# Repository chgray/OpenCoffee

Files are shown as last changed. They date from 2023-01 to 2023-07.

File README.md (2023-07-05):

# KiCad
 - to make the file load pcbnew and then do File->Fabrication Outputs.  save a .pos file {CSV, millimeters, seperate files for front/back} -> Generate Position File.  (chgray-keyboard-top-pos.csv)
	A) Change Ref to Designator
	B) Rot to Rotation
	C) Side to Layer
	D) PoxX to "Mid X"
	E) PosY to "Mid Y"
 
 - to make the BOM load eeschema and then do the button ("generate bill of material") BOM -> bom2csv
     you're looking for chgray-keyboard.csv
	A) Change Reference to "Designator"
	B) Change Datasheet to "JLCPCB Part #"
	C) Value to Comment

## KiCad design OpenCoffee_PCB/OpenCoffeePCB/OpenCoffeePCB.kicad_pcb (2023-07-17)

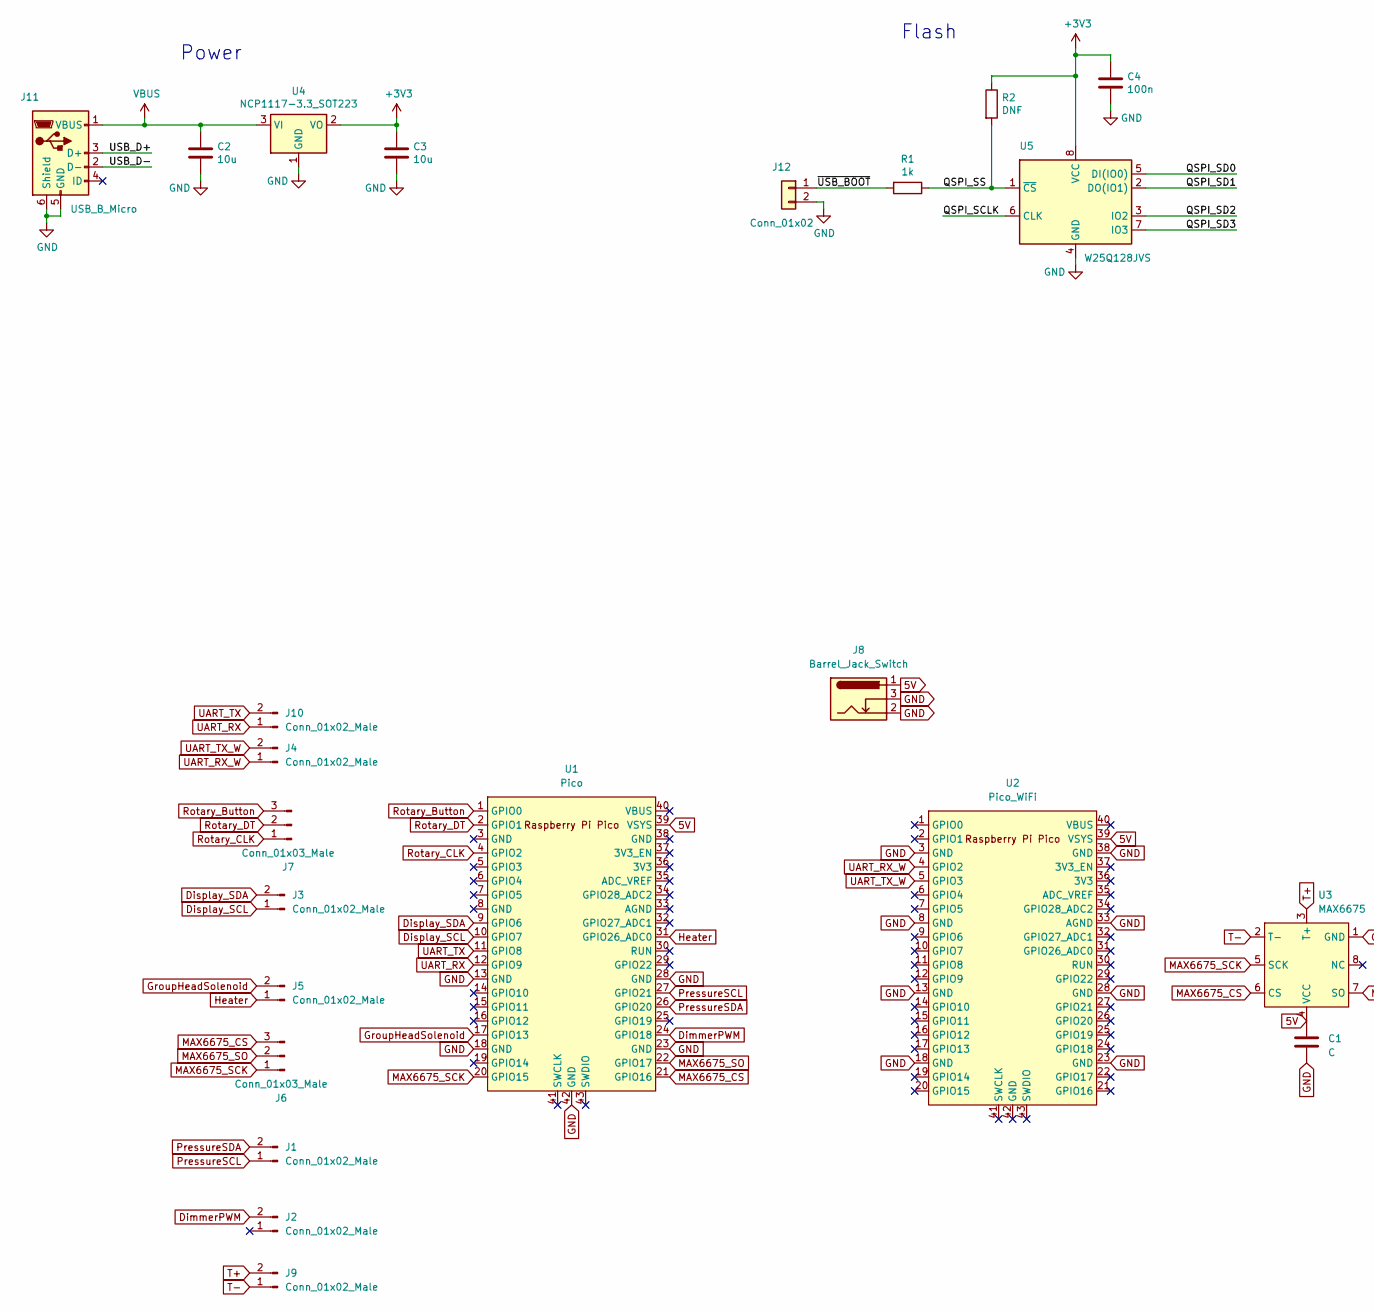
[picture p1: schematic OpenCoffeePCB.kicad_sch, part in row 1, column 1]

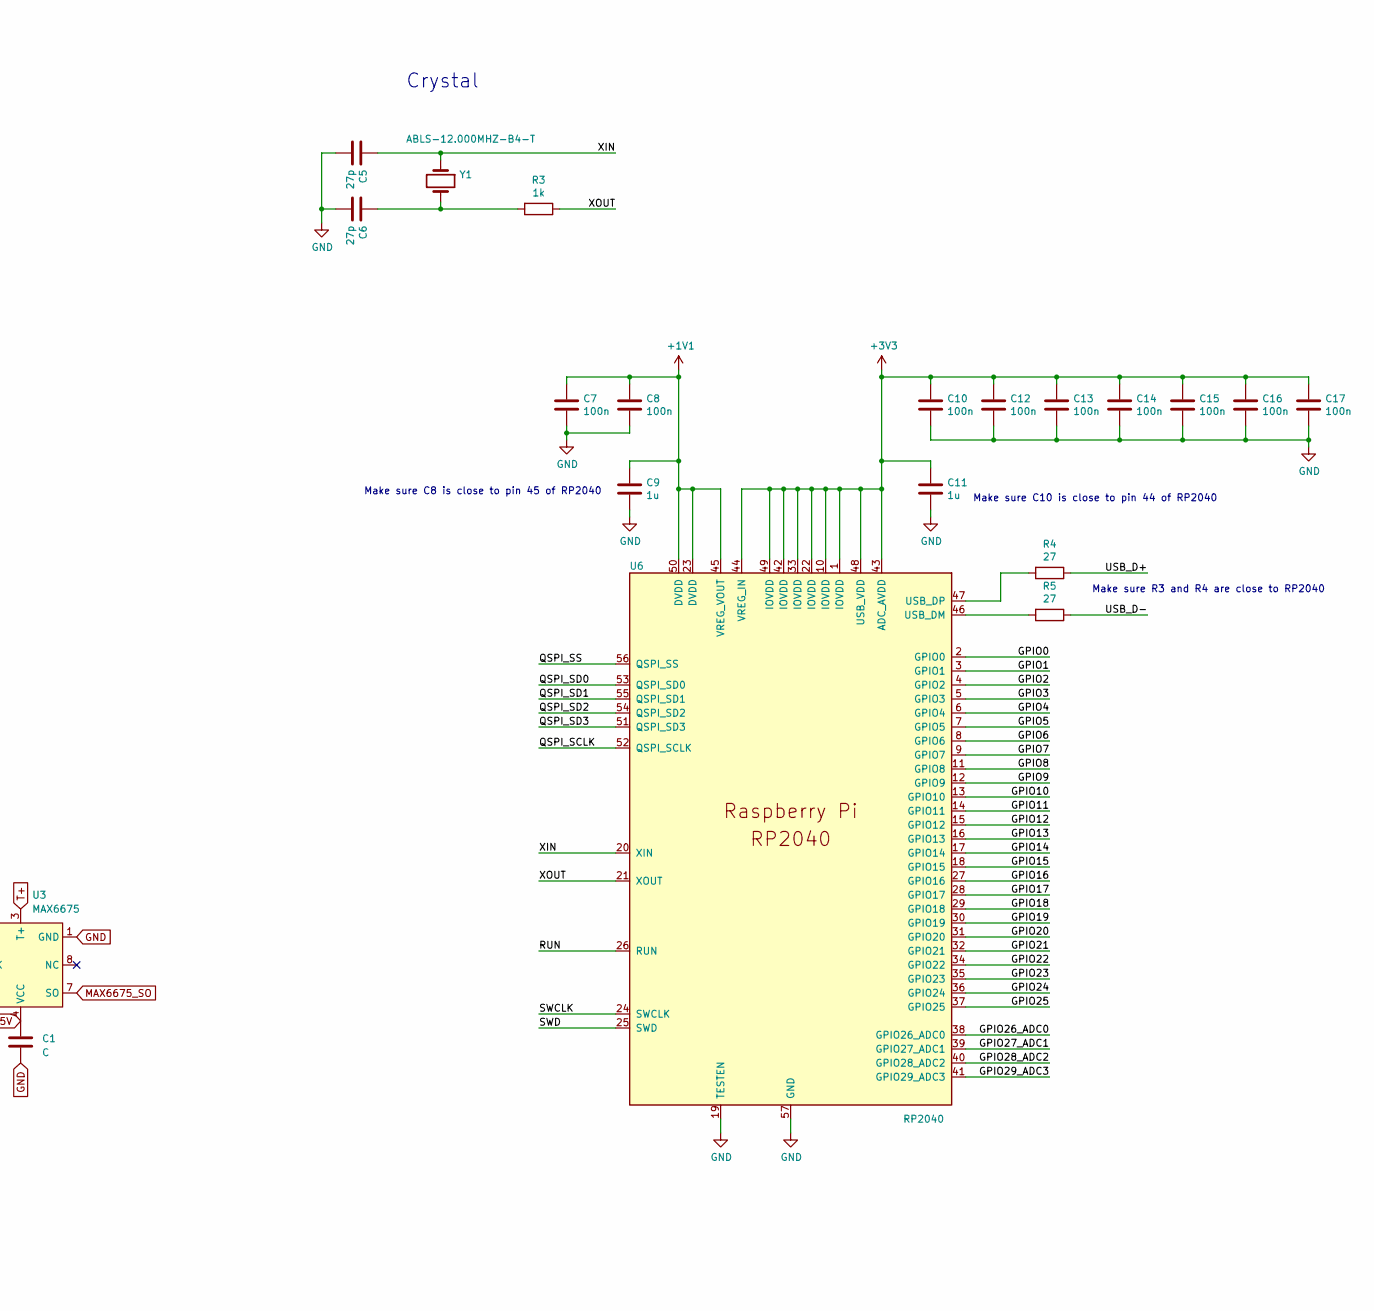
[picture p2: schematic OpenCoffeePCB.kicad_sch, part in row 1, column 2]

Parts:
C1: C; C_0805_2012Metric
C2, C3: 10u; C_0805_2012Metric
C4, C7, C8, C10, C12, C13, C14, C15, C16, C17: 100n; C_0402_1005Metric
C5, C6: 27p; C_0402_1005Metric
C9, C11: 1u; C_0402_1005Metric
J1, J2, J3, J4, J5, J9, J10: Conn_01x02_Male; Molex_KK-254_AE-6410-02A_1x02_P2.54mm_Vertical
J6, J7: Conn_01x03_Male; Molex_KK-254_AE-6410-03A_1x03_P2.54mm_Vertical
J8: Barrel_Jack_Switch; BarrelJack_GCT_DCJ200-10-A_Horizontal
J11: USB_B_Micro; USB_Micro-B_Amphenol_10103594-0001LF_Horizontal_modified
J12: Conn_01x02; PinHeader_1x02_P2.54mm_Vertical
R1, R3: 1k; C_0402_1005Metric
R2: DNF; C_0402_1005Metric
R4, R5: 27; C_0402_1005Metric
U1: Pico; RPi_Pico_SMD_TH
U2: Pico_WiFi; RPi_Pico_SMD_TH_WIFI
U3: MAX6675
U4: NCP1117-3.3_SOT223; SOT-223-3_TabPin2
U5: W25Q128JVS; SOIC-8_5.23x5.23mm_P1.27mm
U6: RP2040; RP2040-QFN-56
Y1: ABLS-12.000MHZ-B4-T; Crystal_SMD_HC49-US

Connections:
5V: C1.1, J8.1, U1.39 (VSYS), U2.39 (VSYS), U3.4 (VCC)
+1V1: C7.1, C8.1, C9.1, U6.23 (DVDD), U6.45 (VREG_VOUT), U6.50 (DVDD)
+3V3: C3.1, C4.1, C10.1, C11.1, C12.1, C13.1, C14.1, C15.1, C16.1, C17.1, R2.1, U4.2 (VO), U5.8 (VCC), U6.1 (IOVDD), U6.10 (IOVDD), U6.22 (IOVDD), U6.33 (IOVDD), U6.42 (IOVDD), U6.43 (ADC_AVDD), U6.44 (VREG_IN), U6.48 (USB_VDD), U6.49 (IOVDD)
/GPIO0: U6.2 (GPIO0)
/GPIO1: U6.3 (GPIO1)
/GPIO2: U6.4 (GPIO2)
/GPIO3: U6.5 (GPIO3)
/GPIO4: U6.6 (GPIO4)
/GPIO5: U6.7 (GPIO5)
/GPIO6: U6.8 (GPIO6)
/GPIO7: U6.9 (GPIO7)
/GPIO8: U6.11 (GPIO8)
/GPIO9: U6.12 (GPIO9)
/GPIO10: U6.13 (GPIO10)
/GPIO11: U6.14 (GPIO11)
/GPIO12: U6.15 (GPIO12)
/GPIO13: U6.16 (GPIO13)
/GPIO14: U6.17 (GPIO14)
/GPIO15: U6.18 (GPIO15)
/GPIO16: U6.27 (GPIO16)
/GPIO17: U6.28 (GPIO17)
/GPIO18: U6.29 (GPIO18)
/GPIO19: U6.30 (GPIO19)
/GPIO20: U6.31 (GPIO20)
/GPIO21: U6.32 (GPIO21)
/GPIO22: U6.34 (GPIO22)
/GPIO23: U6.35 (GPIO23)
/GPIO24: U6.36 (GPIO24)
/GPIO25: U6.37 (GPIO25)
/GPIO26_ADC0: U6.38 (GPIO26_ADC0)
/GPIO27_ADC1: U6.39 (GPIO27_ADC1)
/GPIO28_ADC2: U6.40 (GPIO28_ADC2)
/GPIO29_ADC3: U6.41 (GPIO29_ADC3)
/QSPI_SCLK: U5.6 (CLK), U6.52 (QSPI_SCLK)
/QSPI_SD0: U5.5 (DI(IO0)), U6.53 (QSPI_SD0)
/QSPI_SD1: U5.2 (DO(IO1)), U6.55 (QSPI_SD1)
/QSPI_SD2: U5.3 (IO2), U6.54 (QSPI_SD2)
/QSPI_SD3: U5.7 (IO3), U6.51 (QSPI_SD3)
/QSPI_SS: R1.1, R2.2, U5.1 (~CS), U6.56 (QSPI_SS)
/RUN: U6.26 (RUN)
/SWCLK: U6.24 (SWCLK)
/SWD: U6.25 (SWD)
/USB_D+: J11.3 (D+), R4.1
/USB_D-: J11.2 (D-), R5.1
/XIN: C5.1, U6.20 (XIN), Y1.1
/XOUT: R3.1, U6.21 (XOUT)
/~USB_BOOT: J12.1, R1.2
DimmerPWM: J2.2, U1.24 (GPIO18)
Display_SCL: J3.1, U1.10 (GPIO7)
Display_SDA: J3.2, U1.9 (GPIO6)
GND: C1.2, C2.2, C3.2, C4.2, C5.2, C6.2, C7.2, C8.2, C9.2, C10.2, C11.2, C12.2, C13.2, C14.2, C15.2, C16.2, C17.2, J8.2, J8.3, J11.5 (GND), J11.6 (Shield), J12.2, U1.13 (GND), U1.18 (GND), U1.23 (GND), U1.28 (GND), U1.42 (GND), U2.3 (GND), U2.8 (GND), U2.13 (GND), U2.18 (GND), U2.23 (GND), U2.28 (GND), U2.33 (AGND), U2.38 (GND), U3.1 (GND), U4.1 (GND), U5.4 (GND), U6.19 (TESTEN), U6.57 (GND)
GroupHeadSolenoid: J5.2, U1.17 (GPIO13)
Heater: J5.1, U1.31 (GPIO26_ADC0)
MAX6675_CS: J6.3, U1.21 (GPIO16), U3.6 (CS)
MAX6675_SCK: J6.1, U1.20 (GPIO15), U3.5 (SCK)
MAX6675_SO: J6.2, U1.22 (GPIO17), U3.7 (SO)
unnamed: C6.1, R3.2, Y1.2
unnamed: R5.2, U6.46 (USB_DM)
unnamed: R4.2, U6.47 (USB_DP)
PressureSCL: J1.1, U1.27 (GPIO21)
PressureSDA: J1.2, U1.26 (GPIO20)
Rotary_Button: J7.3, U1.1 (GPIO0)
Rotary_CLK: J7.1, U1.4 (GPIO2)
Rotary_DT: J7.2, U1.2 (GPIO1)
T+: J9.2, U3.3 (T+)
T-: J9.1, U3.2 (T-)
UART_RX: J10.1, U1.12 (GPIO9)
UART_RX_W: J4.1, U2.4 (GPIO2)
UART_TX: J10.2, U1.11 (GPIO8)
UART_TX_W: J4.2, U2.5 (GPIO3)
VBUS: C2.1, J11.1 (VBUS), U4.3 (VI)

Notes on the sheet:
Make sure C8 is close to pin 45 of RP2040
Power
Make sure C10 is close to pin 44 of RP2040
Crystal
Flash
Make sure R3 and R4 are close to RP2040

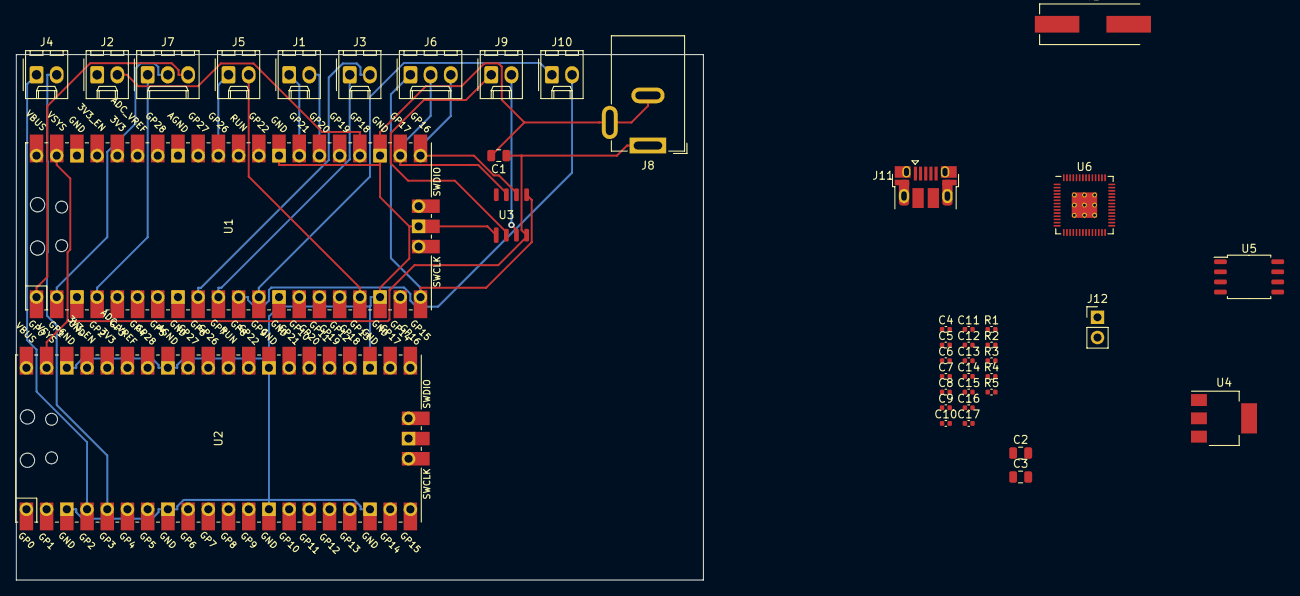
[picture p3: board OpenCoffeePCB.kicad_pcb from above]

Board: 2 copper layers, 86.4 x 66.0 mm, 41 parts (0 on the bottom side), 38 nets.

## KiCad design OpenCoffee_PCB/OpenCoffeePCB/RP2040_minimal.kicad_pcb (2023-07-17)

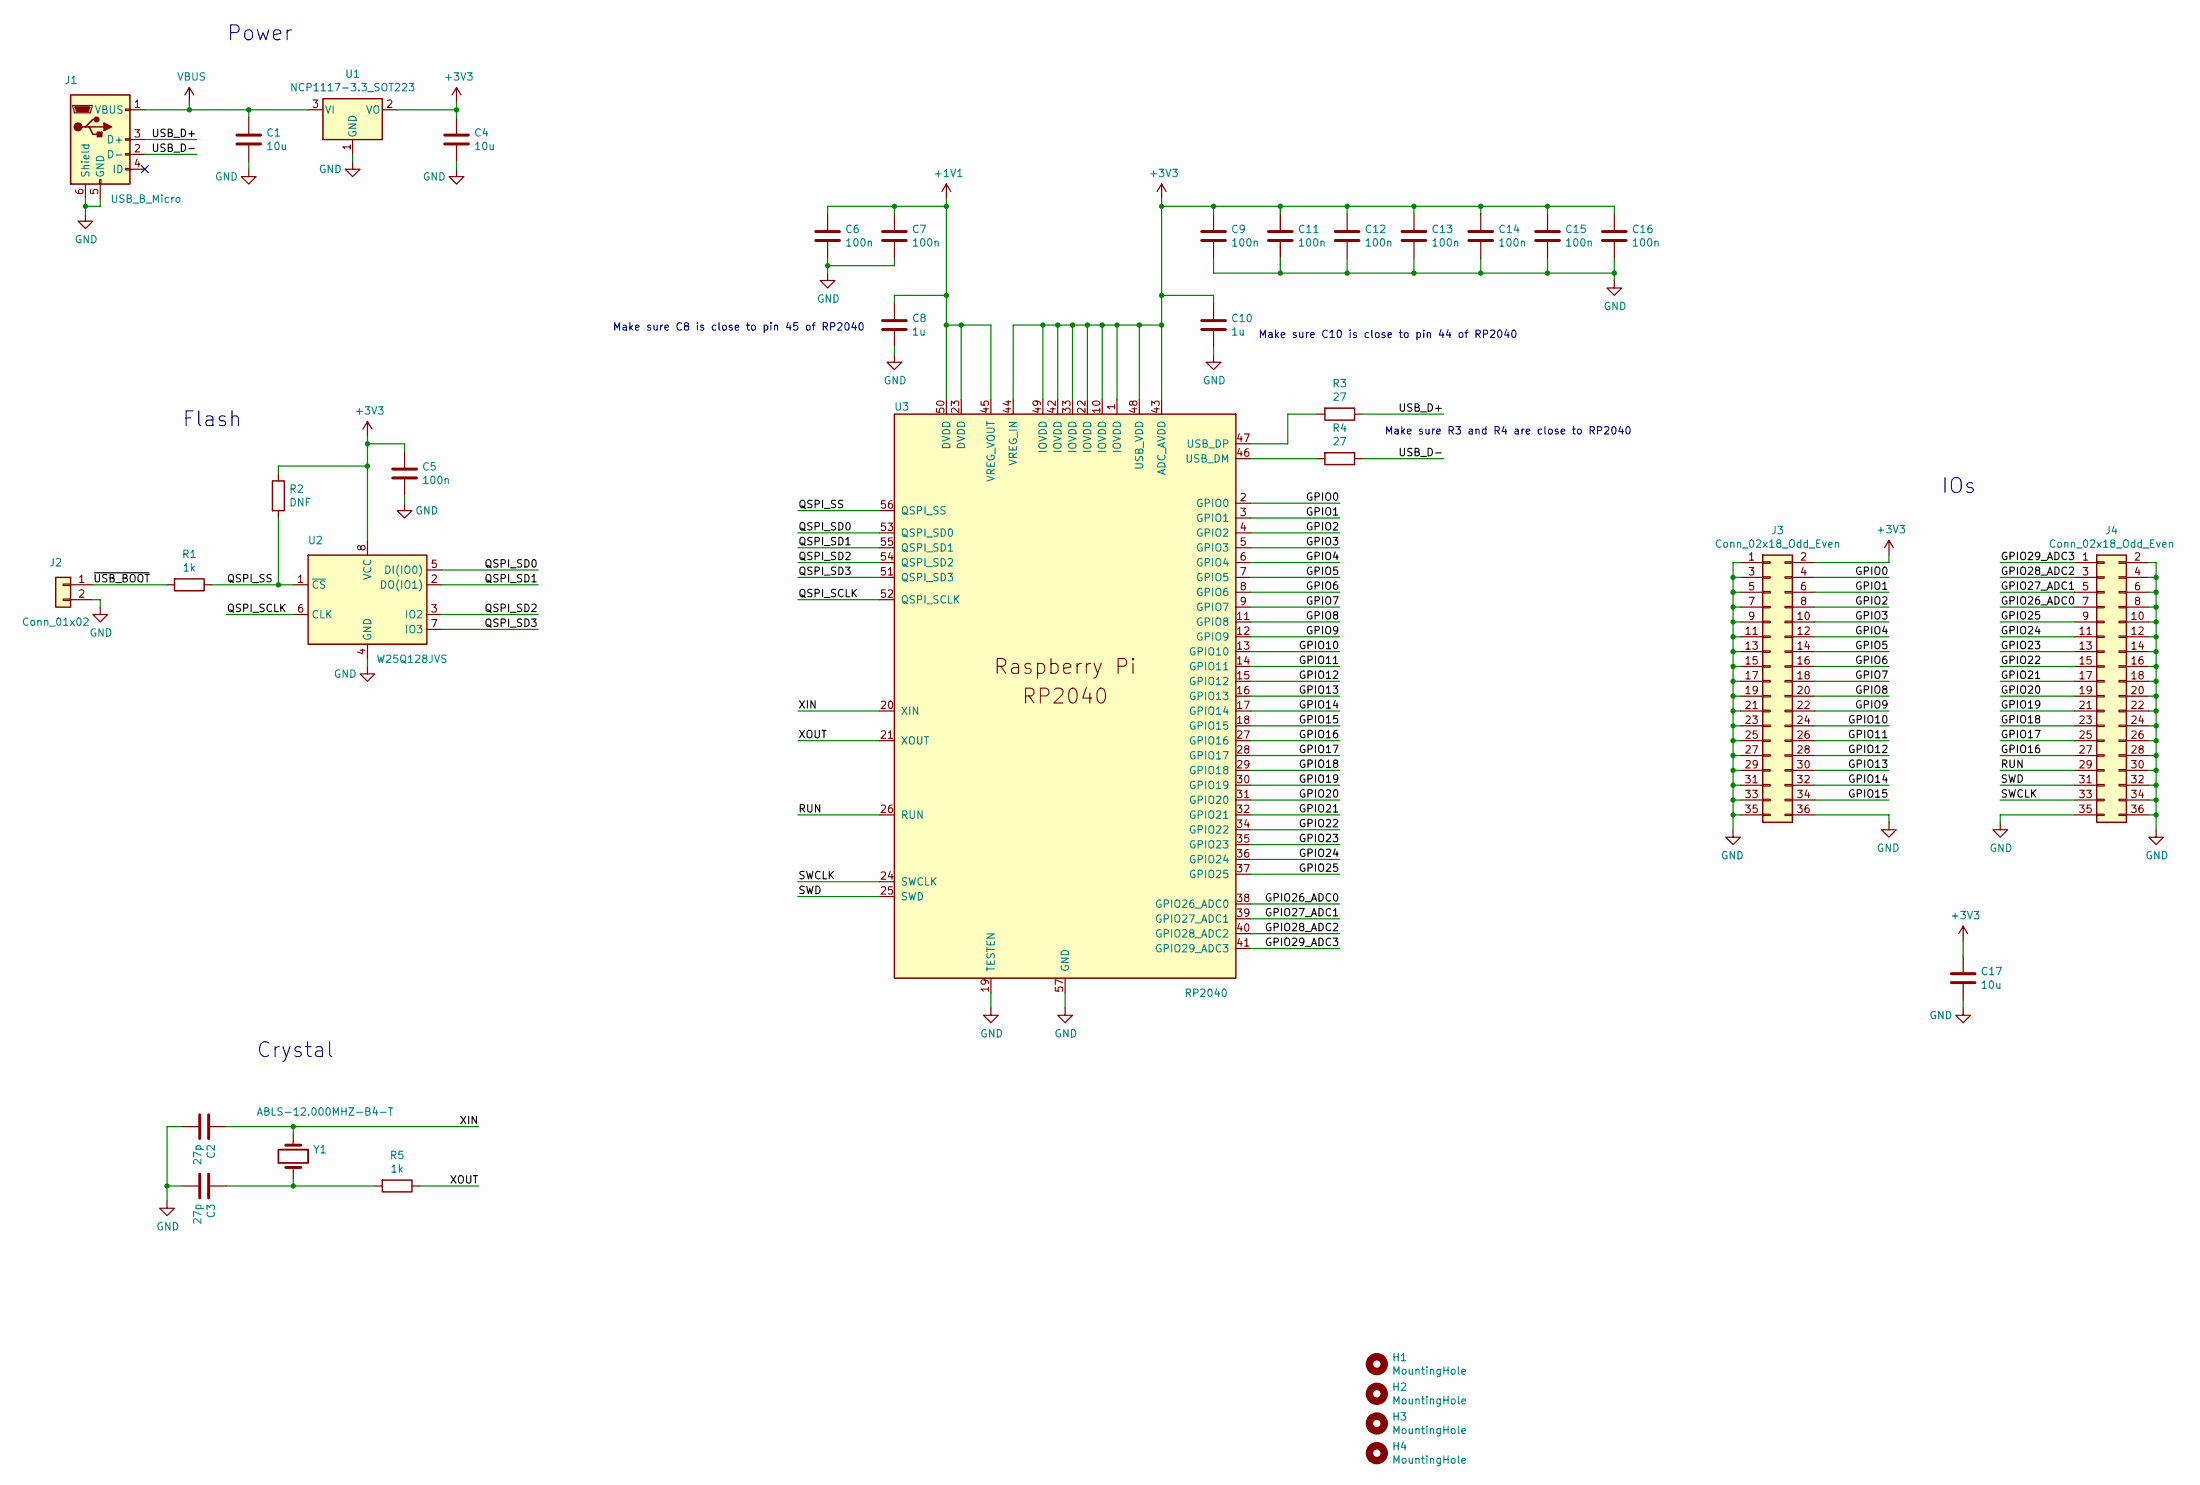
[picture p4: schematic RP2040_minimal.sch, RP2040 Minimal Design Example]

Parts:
C1, C4, C17: 10u; C_0805_2012Metric
C2, C3: 27p; C_0402_1005Metric
C5, C6, C7, C9, C11, C12, C13, C14, C15, C16: 100n; C_0402_1005Metric
C8, C10: 1u; C_0402_1005Metric
H1, H2, H3, H4: MountingHole; MountingHole_2.7mm_M2.5
J1: USB_B_Micro; USB_Micro-B_Amphenol_10103594-0001LF_Horizontal_modified
J2: Conn_01x02; PinHeader_1x02_P2.54mm_Vertical
J3, J4: Conn_02x18_Odd_Even; PinHeader_2x18_P2.54mm_Vertical
R1, R5: 1k; C_0402_1005Metric
R2: DNF; C_0402_1005Metric
R3, R4: 27; C_0402_1005Metric
U1: NCP1117-3.3_SOT223; SOT-223-3_TabPin2
U2: W25Q128JVS; SOIC-8_5.23x5.23mm_P1.27mm
U3: RP2040; RP2040-QFN-56
Y1: ABLS-12.000MHZ-B4-T; Crystal_SMD_HC49-US

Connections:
+1V1: C6.1, C7.1, C8.1, U3.23 (DVDD), U3.45 (VREG_VOUT), U3.50 (DVDD)
+3V3: C4.1, C5.1, C9.1, C10.1, C11.1, C12.1, C13.1, C14.1, C15.1, C16.1, C17.1, J3.2, R2.1, U1.2 (VO), U2.8 (VCC), U3.1 (IOVDD), U3.10 (IOVDD), U3.22 (IOVDD), U3.33 (IOVDD), U3.42 (IOVDD), U3.43 (ADC_AVDD), U3.44 (VREG_IN), U3.48 (USB_VDD), U3.49 (IOVDD)
/GPIO0: J3.4, U3.2 (GPIO0)
/GPIO1: J3.6, U3.3 (GPIO1)
/GPIO2: J3.8, U3.4 (GPIO2)
/GPIO3: J3.10, U3.5 (GPIO3)
/GPIO4: J3.12, U3.6 (GPIO4)
/GPIO5: J3.14, U3.7 (GPIO5)
/GPIO6: J3.16, U3.8 (GPIO6)
/GPIO7: J3.18, U3.9 (GPIO7)
/GPIO8: J3.20, U3.11 (GPIO8)
/GPIO9: J3.22, U3.12 (GPIO9)
/GPIO10: J3.24, U3.13 (GPIO10)
/GPIO11: J3.26, U3.14 (GPIO11)
/GPIO12: J3.28, U3.15 (GPIO12)
/GPIO13: J3.30, U3.16 (GPIO13)
/GPIO14: J3.32, U3.17 (GPIO14)
/GPIO15: J3.34, U3.18 (GPIO15)
/GPIO16: J4.27, U3.27 (GPIO16)
/GPIO17: J4.25, U3.28 (GPIO17)
/GPIO18: J4.23, U3.29 (GPIO18)
/GPIO19: J4.21, U3.30 (GPIO19)
/GPIO20: J4.19, U3.31 (GPIO20)
/GPIO21: J4.17, U3.32 (GPIO21)
/GPIO22: J4.15, U3.34 (GPIO22)
/GPIO23: J4.13, U3.35 (GPIO23)
/GPIO24: J4.11, U3.36 (GPIO24)
/GPIO25: J4.9, U3.37 (GPIO25)
/GPIO26_ADC0: J4.7, U3.38 (GPIO26_ADC0)
/GPIO27_ADC1: J4.5, U3.39 (GPIO27_ADC1)
/GPIO28_ADC2: J4.3, U3.40 (GPIO28_ADC2)
/GPIO29_ADC3: J4.1, U3.41 (GPIO29_ADC3)
/QSPI_SCLK: U2.6 (CLK), U3.52 (QSPI_SCLK)
/QSPI_SD0: U2.5 (DI(IO0)), U3.53 (QSPI_SD0)
/QSPI_SD1: U2.2 (DO(IO1)), U3.55 (QSPI_SD1)
/QSPI_SD2: U2.3 (IO2), U3.54 (QSPI_SD2)
/QSPI_SD3: U2.7 (IO3), U3.51 (QSPI_SD3)
/QSPI_SS: R1.1, R2.2, U2.1 (~CS), U3.56 (QSPI_SS)
/RUN: J4.29, U3.26 (RUN)
/SWCLK: J4.33, U3.24 (SWCLK)
/SWD: J4.31, U3.25 (SWD)
/USB_D+: J1.3 (D+), R3.1
/USB_D-: J1.2 (D-), R4.1
/XIN: C2.1, U3.20 (XIN), Y1.1
/XOUT: R5.1, U3.21 (XOUT)
/~USB_BOOT: J2.1, R1.2
GND: C1.2, C2.2, C3.2, C4.2, C5.2, C6.2, C7.2, C8.2, C9.2, C10.2, C11.2, C12.2, C13.2, C14.2, C15.2, C16.2, C17.2, J1.5 (GND), J1.6 (Shield), J2.2, J3.1, J3.3, J3.5, J3.7, J3.9, J3.11, J3.13, J3.15, J3.17, J3.19, J3.21, J3.23, J3.25, J3.27, J3.29, J3.31, J3.33, J3.35, J3.36, J4.2, J4.4, J4.6, J4.8, J4.10, J4.12, J4.14, J4.16, J4.18, J4.20, J4.22, J4.24, J4.26, J4.28, J4.30, J4.32, J4.34, J4.35, J4.36, U1.1 (GND), U2.4 (GND), U3.19 (TESTEN), U3.57 (GND)
unnamed: C3.1, R5.2, Y1.2
unnamed: R3.2, U3.47 (USB_DP)
unnamed: R4.2, U3.46 (USB_DM)
VBUS: C1.1, J1.1 (VBUS), U1.3 (VI)

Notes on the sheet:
Make sure C10 is close to pin 44 of RP2040
Make sure C8 is close to pin 45 of RP2040
Crystal
Flash
Power
IOs
Make sure R3 and R4 are close to RP2040

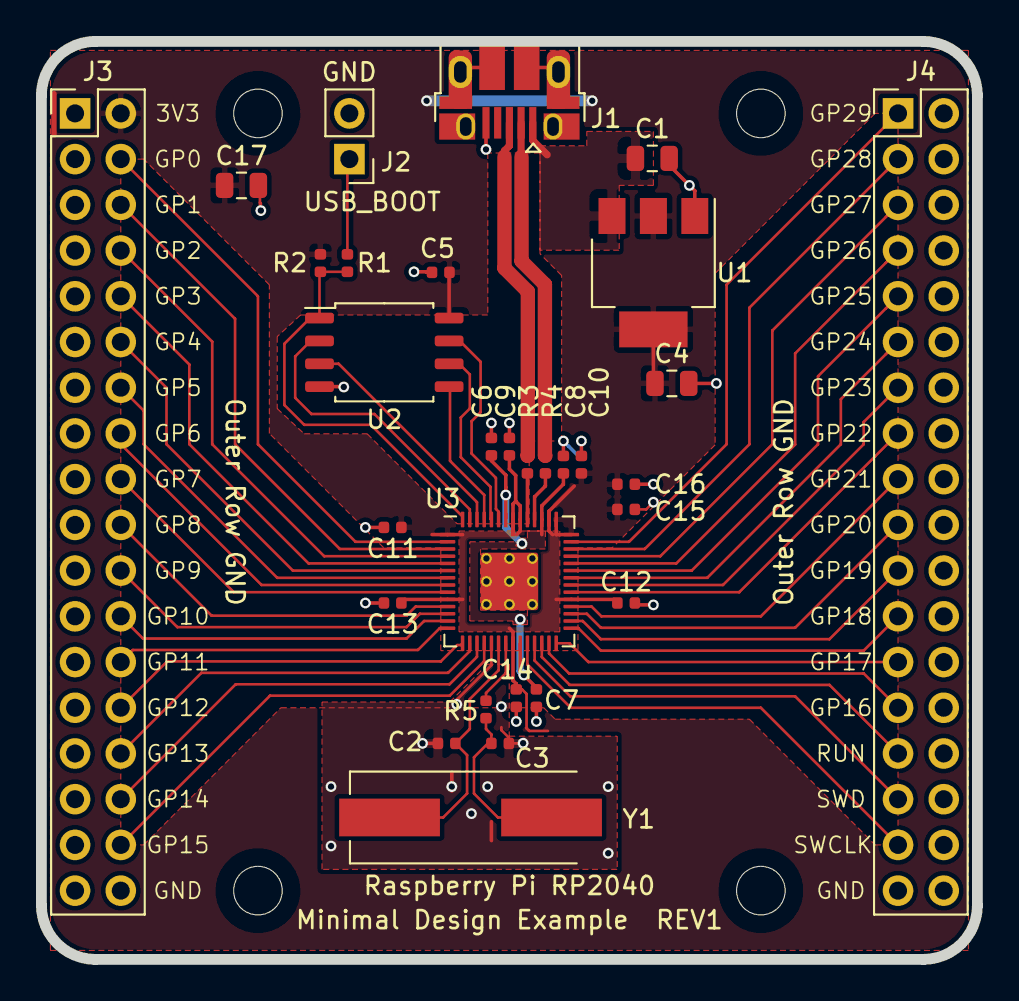
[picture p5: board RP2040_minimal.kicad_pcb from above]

Board: 2 copper layers, 52.0 x 51.0 mm, 34 parts (0 on the bottom side), 51 nets.

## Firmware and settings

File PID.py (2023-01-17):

from machine import Pin, Timer
import time
import machine, onewire, ds18x20
from lcd1602 import *
from PID_lib import *

from time import sleep

global lcd
# https://microcontrollerslab.com/ds18b20-raspberry-pi-pico-micropython-tutorial/

print("Running.")

led = Pin(25, Pin.OUT)
button = Pin(12, Pin.IN, Pin.PULL_DOWN)
timer = Timer()

print("--------------------------------")
count = 0
temp=0.1
heating=1

# PID
# https://github.com/gastmaier/micropython-simple-pid

t0= time.ticks_ms()

def simulate_temp_change(timer):
    global temp
    global t0
    
    if 0 != heating:
        temp = (temp + 0.5)
        led.value(1)
    else:
        temp = (temp - 0.25)
        led.value(0)
        
    if temp < 0:
        temp = 0
    elif temp > 300:
        temp = 300
    
    t= time.ticks_ms() - t0 # t is CPU seconds elapsed (floating point)
    print("%f, %f" % (t, temp))


timer.init(freq=10, mode=Timer.PERIODIC, callback=simulate_temp_change)



# http://brettbeauregard.com/blog/2011/04/improving-the-beginner%e2%80%99s-pid-sample-time/
pid = PID(1, 0.1, 0.05, setpoint=211, scale='ms')

pid.output_limits = (0, 1)    # Output value will be between 0 and 10
pid.set_auto_mode(True, last_output=0)
# Assume we have a system we want to control in controlled_system
# v = controlled_system.update(0)

while True:
    
    # Compute new output from the PID according to the systems current value
    control = pid(temp)
    
    #print("Temp: %f  Control: %d" % (temp, control))
    heating = control
    
    sleep(.1)
    
    b = button.value()
    if 0 == button.value():
        print("Button")
        temp = temp - 2
    
    # Feed the PID output to the system and get its current value
    # v = controlled_system.update(control)
















while 1:
    b = button.value()
    
    try:
        count = count + 1
        print("Temp : %f" % (temp))
        
        if temp > 3:
            heating = 0
            
        sleep(2)
        if 0 == button.value():
            print("button")
            count += 100
            sleep(1)
            
    except Exception as e:
        print(e)
        print("Not good..")
        
        
    
 

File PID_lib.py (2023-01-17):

import utime

def _clamp(value, limits):
    lower, upper = limits
    if value is None:
        return None
    elif (upper is not None) and (value > upper):
        return upper
    elif (lower is not None) and (value < lower):
        return lower
    return value

class PID(object):
    """A simple PID controller."""

    def __init__(
        self,
        Kp=1.0,
        Ki=0.0,
        Kd=0.0,
        setpoint=0,
        sample_time=None,
        scale='s',
        output_limits=[None, None],
        auto_mode=True,
        proportional_on_measurement=False,
        error_map=None
    ):
        """
        Initialize a new PID controller.

        :param Kp: The value for the proportional gain Kp
        :param Ki: The value for the integral gain Ki
        :param Kd: The value for the derivative gain Kd
        :param setpoint: The initial setpoint that the PID will try to achieve
        :param sample_time: The interval in the setted scale which the controller should wait before generating
            a new output value. The PID works best when it is constantly called (eg. during a
            loop), but with a sample time set so that the time difference between each update is
            (close to) constant. If set to None, the PID will compute a new output value every time
            it is called, keep None to use param dt for timestep.
        :param scale: Set the scale of the controller, accepted values are 's' for seconds, 'ms' for
            miliseconds, 'us' for microseconds, 'ns' for nanoscondas and 'cpu' for the highest precision
            at cpu clock. On default and on error set to seconds.
        :param output_limits: The initial output limits to use, given as an iterable with 2
            elements, for example: (lower, upper). The output will never go below the lower limit
            or above the upper limit. Either of the limits can also be set to None to have no limit
            in that direction. Setting output limits also avoids integral windup, since the
            integral term will never be allowed to grow outside of the limits.
        :param auto_mode: Whether the controller should be enabled (auto mode) or not (manual mode)
        :param proportional_on_measurement: Whether the proportional term should be calculated on
            the input directly rather than on the error (which is the traditional way). Using
            proportional-on-measurement avoids overshoot for some types of systems.
        :param error_map: Function to transform the error value in another constrained value.
        """
        self.Kp, self.Ki, self.Kd = Kp, Ki, Kd
        self.setpoint = setpoint
        self.sample_time = sample_time

        def get_scale(x):
            return {
                's' : 'time',
                'ms': 'ticks_ms',
                'us': 'ticks_us',
                'ns': 'time_ns',
                'cpu':'ticks_cpu'
            }.get(x, 'time') # seconds is default if x is not found
        self.scale = get_scale(scale)

        def get_unit(x):
            return {
                's' : 1,
                'ms': 1e-3,
                'us': 1e-6,
                'ns': 1e-9,
                'cpu':1
            }.get(x, 1) # tunings should be explicitly defined at 'ticks_cpu'
        self.unit = get_unit(scale)

        if hasattr(utime, self.scale) and callable(func := getattr(utime, self.scale)):
            self.time = func

        self._min_output, self._max_output = None, None
        self._auto_mode = auto_mode
        self.proportional_on_measurement = proportional_on_measurement
        self.error_map = error_map

        self._proportional = 0
        self._integral = 0
        self._derivative = 0

        self._last_time = None
        self._last_output = None
        self._last_input = None

        self.output_limits = output_limits
        self.reset()

    def __call__(self, input_, dt=None):
        """
        Update the PID controller.

        Call the PID controller with *input_* and calculate and return a control output if
        sample_time has passed since the last update. If no new output is calculated,
        return the previous output instead (or None if no value has been calculated yet).

        :param dt: If set, uses this value for timestep instead of real time. This can be used in
            simulations when simulation time is different from real time.
        """
        if not self.auto_mode:
            return self._last_output

        now = self.time()
        if dt is None:
            dt = utime.ticks_diff(now,self._last_time) if (utime.ticks_diff(now,self._last_time)) else 1e-16
        elif dt <= 0:
            raise ValueError('dt has negative value {}, must be positive'.format(dt))

        if self.sample_time is not None and dt < self.sample_time and self._last_output is not None:
            # Only update every sample_time
            return self._last_output

        # Compute error terms
        error = self.setpoint - input_
        d_input = input_ - (self._last_input if (self._last_input is not None) else input_)

        # Check if must map the error
        if self.error_map is not None:
            error = self.error_map(error)

        # Compute the proportional term
        if not self.proportional_on_measurement:
            # Regular proportional-on-error, simply set the proportional term
            self._proportional = self.Kp * error
        else:
            # Add the proportional error on measurement to error_sum
            self._proportional -= self.Kp * self.unit * d_input

        # Compute integral and derivative terms
        self._integral += (self.Ki * self.unit) * error * dt
        self._integral = _clamp(self._integral, self.output_limits)  # Avoid integral windup

        self._derivative = -(self.Kd / self.unit) * d_input / dt

        # Compute final output
        output = self._proportional + self._integral + self._derivative
        output = _clamp(output, self.output_limits)

        # Keep track of state
        self._last_output = output
        self._last_input = input_
        self._last_time = now

        return output

    def __repr__(self):
        return (
            '{self.__class__.__name__}('
            'Kp={self.Kp!r}, Ki={self.Ki!r}, Kd={self.Kd!r}, '
            'setpoint={self.setpoint!r}, sample_time={self.sample_time!r}, '
            'output_limits={self.output_limits!r}, auto_mode={self.auto_mode!r}, '
            'proportional_on_measurement={self.proportional_on_measurement!r},'
            'error_map={self.error_map!r}'
            ')'
        ).format(self=self)

    @property
    def components(self):
        """
        The P-, I- and D-terms from the last computation as separate components as a tuple. Useful
        for visualizing what the controller is doing or when tuning hard-to-tune systems.
        """
        return self._proportional, self._integral, self._derivative
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

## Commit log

2023-01-31 pid stuff
2023-02-13 steam finish
    [StoreSteamPID.csv]
2023-02-26 add pressure
2023-03-06 relay commands over UART
2023-03-13 add dimmer to motor
2023-03-27 ADC experiment
2023-03-28 voltage working
2023-04-07 updates pcb
    [OpenCoffeePCB.kicad_pcb, OpenCoffeePCB.kicad_sch]
2023-06-05 intial layout
    [OpenCoffeePCB.kicad_pcb, OpenCoffeePCB.kicad_sch]
2023-06-05 working on max6675
    [OpenCoffeePCB.kicad_pcb, OpenCoffeePCB.kicad_sch]
2023-06-11 working on pcb
    [OpenCoffeePCB.kicad_pcb, OpenCoffeePCB.kicad_sch]
2023-07-04 making PCB
    [OpenCoffeePCB.kicad_pcb, OpenCoffeePCB.kicad_sch]
2023-07-04 shipped pcb1
    [OpenCoffeePCB.kicad_sch]
2023-07-17 added RP2040 from https://datasheets.raspberrypi.com/rp2040/Minimal-KiCAD.zip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..
    [OpenCoffeePCB.kicad_pcb, OpenCoffeePCB.kicad_sch]
